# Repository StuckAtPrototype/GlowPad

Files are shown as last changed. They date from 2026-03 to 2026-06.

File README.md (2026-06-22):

# GlowPad

A multi-mode interactive pad built on the ESP32-S3 with 5 capacitive touch keys, 5 WS2812B LEDs, and a piezo buzzer. Supports five modes: a Pomodoro timer, a pentatonic piano, a Simon-style memory game, a reaction speed game, and a USB media-control (keyboard) mode for music players.

## Hardware

| Peripheral | Details |
|---|---|
| MCU | ESP32-S3-WROOM-1 |
| Touch inputs | 5 capacitive pads (CAP1-CAP5) on GPIO 4, 5, 3, 2, 1 |
| LEDs | 5x IN-PI15TAT5R5G5B (WS2812B) chain on GPIO 21 (via BSS138 level shifter) |
| Buzzer | Piezo (SMT1240SHT) on GPIO 48 (via transistor driver) |
| USB | Native USB-C (D+/D− on GPIO 20/19) for HID + programming |
| Power | AP2205 3.3V LDO |

### PCB / Design Files

The board is designed in [KiCad](https://www.kicad.org/) (v8+). Design sources and
manufacturing outputs live under `hardware/GlowPad/`:

| File / Folder | Contents |
|---|---|
| `GlowPad.kicad_pro` | KiCad project file |
| `GlowPad.kicad_sch` | Schematic |
| `GlowPad.kicad_pcb` | PCB layout |
| `GlowPad_BOM.csv` | Bill of materials |
| `gerber/` | Gerber + drill files for fabrication |

To open the design, launch KiCad and open `hardware/GlowPad/GlowPad.kicad_pro`.

#### Key components (see `GlowPad_BOM.csv` for the full BOM)

| Ref | Part | Function |
|---|---|---|
| U1 | ESP32-S3-WROOM-1 | MCU |
| U6 | AP2205-33 | 3.3V LDO regulator |
| Q1 | BSS138 | LED data level shifter |
| D5 | TPD1E10B06 | USB ESD protection |
| J1 | USB4105-GF-A | USB-C connector |
| LED1-5 | IN-PI15TAT5R5G5B | Addressable RGB LEDs |
| TCH1-5 | Capacitive pads | Touch keys |
| LS1 | SMT1240SHT | Piezo buzzer |
| SW1 / SW2 | RKB2 tactile | Reset / Boot (enable) |

## Modes

Switch modes by long-pressing keys 1–5 (pads 1–5).

### 1. Pomodoro Timer (key 1 long press)

A focus timer with five preset durations mapped to the five keys:

| Key | Duration |
|---|---|
| 1 | 5 min |
| 2 | 10 min |
| 3 | 25 min |
| 4 | 45 min |
| 5 | 60 min |

LEDs show a green progress bar while running. After the timer completes, a 60-second grace period starts (pulsing green). If not dismissed, it enters a 60-second alert with pulsing red LEDs and an audible jingle.

**Idle LEDs:** cyan at 30%.

### 2. Piano (key 2 long press)

Each key plays a note from the C-major pentatonic scale:

| Key | Note | Frequency |
|---|---|---|
| 1 | C5 | 523 Hz |
| 2 | D5 | 587 Hz |
| 3 | E5 | 659 Hz |
| 4 | G5 | 784 Hz |
| 5 | A5 | 880 Hz |

The corresponding LED flashes its colour at full brightness while the note plays, then fades back to a dim rainbow idle pattern.

**Idle LEDs:** rainbow (red, yellow, green, cyan, blue) at 20%.

### 3. Memory Game (key 3 long press)

A Simon-style memory game. The system plays an ever-growing random sequence of lights and tones. The player must repeat the sequence by pressing the matching keys in order.

- Each round adds one element to the sequence
- Correct presses flash the key's colour and play its tone
- Wrong press or 3-second timeout ends the game
- Score (rounds completed) is displayed on the LEDs at game over

**Idle LEDs:** yellow at 30%.

### 4. Reaction Game (key 4 long press)

A speed-and-accuracy reaction test over 5 rounds.

1. A random LED lights up after a random delay (0.5-1.5 seconds)
2. Press the matching key as fast as possible
3. Pressing before the LED appears counts as a false start (no penalty, round restarts)
4. After 5 rounds, the score is displayed as 0-5 green LEDs (one per "good" round)

A "good" round requires pressing the correct key in under 450ms. Per-round times and the total time are printed to the serial console.

**Idle LEDs:** purple at 30%.

### 5. Media Control (key 5 long press)

USB HID Consumer (media keys) mode. Connect GlowPad to the host via **native USB** (ESP32-S3 USB D+/D− on GPIO 20/19). The five pads act as media keys:

| Key | Action |
|---|---|
| 1 | Previous track |
| 2 | Play / Pause |
| 3 | Next track |
| 4 | Volume down |
| 5 | Volume up |

Works with most music players (Spotify, VLC, system media keys, etc.). Short press sends the key; the corresponding LED flashes for feedback.

**Idle LEDs:** orange/amber at 30%.

**Note:** Media mode requires the `esp_tinyusb` component (pulled in automatically) and HID enabled in menuconfig (`CONFIG_TINYUSB_HID_ENABLED`). The firmware uses a custom HID Consumer report descriptor.

## Building

Requires [ESP-IDF v5.5+](https://docs.espressif.com/projects/esp-idf/en/stable/esp32s3/get-started/).

```bash
cd GlowPad/firmware
idf.py set-target esp32s3
idf.py build
idf.py -p COMx flash monitor
```

## Project Structure

```
GlowPad/
├── firmware/                # ESP-IDF application
│   └── main/
│       ├── main.c              # Entry point, initialises peripherals and main loop
│       ├── mode_manager.c/h    # Mode switching and dispatch
│       ├── button.c/h          # Capacitive touch driver (ESP32-S3 touch sensor v2)
│       ├── led.c/h             # High-level LED control (progress bar, pulsing, per-LED colour)
│       ├── ws2812_control.c/h  # Low-level WS2812 RMT driver
│       ├── piezo.c/h           # Piezo buzzer driver (LEDC PWM)
│       ├── timer.c/h           # Pomodoro timer state machine
│       ├── piano.c/h           # Piano mode
│       ├── memory_game.c/h     # Simon-style memory game
│       ├── reaction_game.c/h   # Reaction speed game
│       ├── media_control.c/h   # USB HID media keys mode
│       ├── led_color_lib.c/h   # Colour generation utilities
│       └── serial_protocol.c/h # Serial protocol (placeholder)
└── hardware/
    └── GlowPad/             # KiCad project (schematic, PCB, BOM, gerbers)
```

## License

See [LICENSE](LICENSE).

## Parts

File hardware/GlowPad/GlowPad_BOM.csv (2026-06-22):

Id | Designator | Footprint | Quantity | Designation | Supplier and ref
1 | C18,C16,C2,C24,C25,C17 | C_0603_1608Metric | 6 | 0.1uF | CC0603KRX7R7BB104
2 | U1 | ESP32-S3-WROOM-1 | 1 | ESP32-S3-WROOM-1 | ESP32-S3-WROOM-1
3 | D5 | D_SOD-523 | 1 | TPD1E10B06 | TPD1E10B06DYAR
4 | TP1 | TestPoint_Pad_2.0x2.0mm | 1 | TestPoint | DNP
5 | R3,R6,R5 | R_0603_1608Metric | 3 | 470 | ESR03EZPF4700
6 | C1 | C_0603_1608Metric | 1 | 1uF | CC0603KRX5R8BB105
7 | C21,C22 | C_0603_1608Metric | 2 | 10uF | GRM188R61A106ME69D
8 | R4,R2,R1 | R_0603_1608Metric | 3 | 10K | WR06X103 JTL
9 | J1 | GCT_USB4105-GF-A | 1 | USB4105-GF-A | USB4105-GF-A
10 | R17,R18 | R_0603_1608Metric | 2 | 5K1 | RC0603FR-075K1L
11 | D1,D2 | LED_0603_1608Metric | 2 | LED | DNP
12 | TCH1,TCH2,TCH4,TCH5,TCH3 | CapButton_18_26 | 5 | ~ | DNP
13 | LED5,LED4,LED3,LED2,LED1 | IN-PI15_INL | 5 | IN-PI15TAT5R5G5B | IN-PI15TAT5R5G5B
14 | R16,R31 | R_0603_1608Metric | 2 | 1M | RMCF0603FT1M00
15 | U6 | AP2204 | 1 | AP2205 | AP2205-33W5-7
16 | SW1 | SWITCH_0SMTRLFS | 1 | SW_Reset | RKB2SJK250SMTR LFS
17 | SW2 | SWITCH_0SMTRLFS | 1 | SW_Enable | RKB2SJK250SMTR LFS
18 | Q1 | SOT-23 | 1 | BSS138 | BSS138
19 | C3 | C_0603_1608Metric | 1 | 47uF | GRM188C80E476ME05D
20 | LS1 | SMT1240SHT | 1 | SMT1240SHT | SMT1240SHT

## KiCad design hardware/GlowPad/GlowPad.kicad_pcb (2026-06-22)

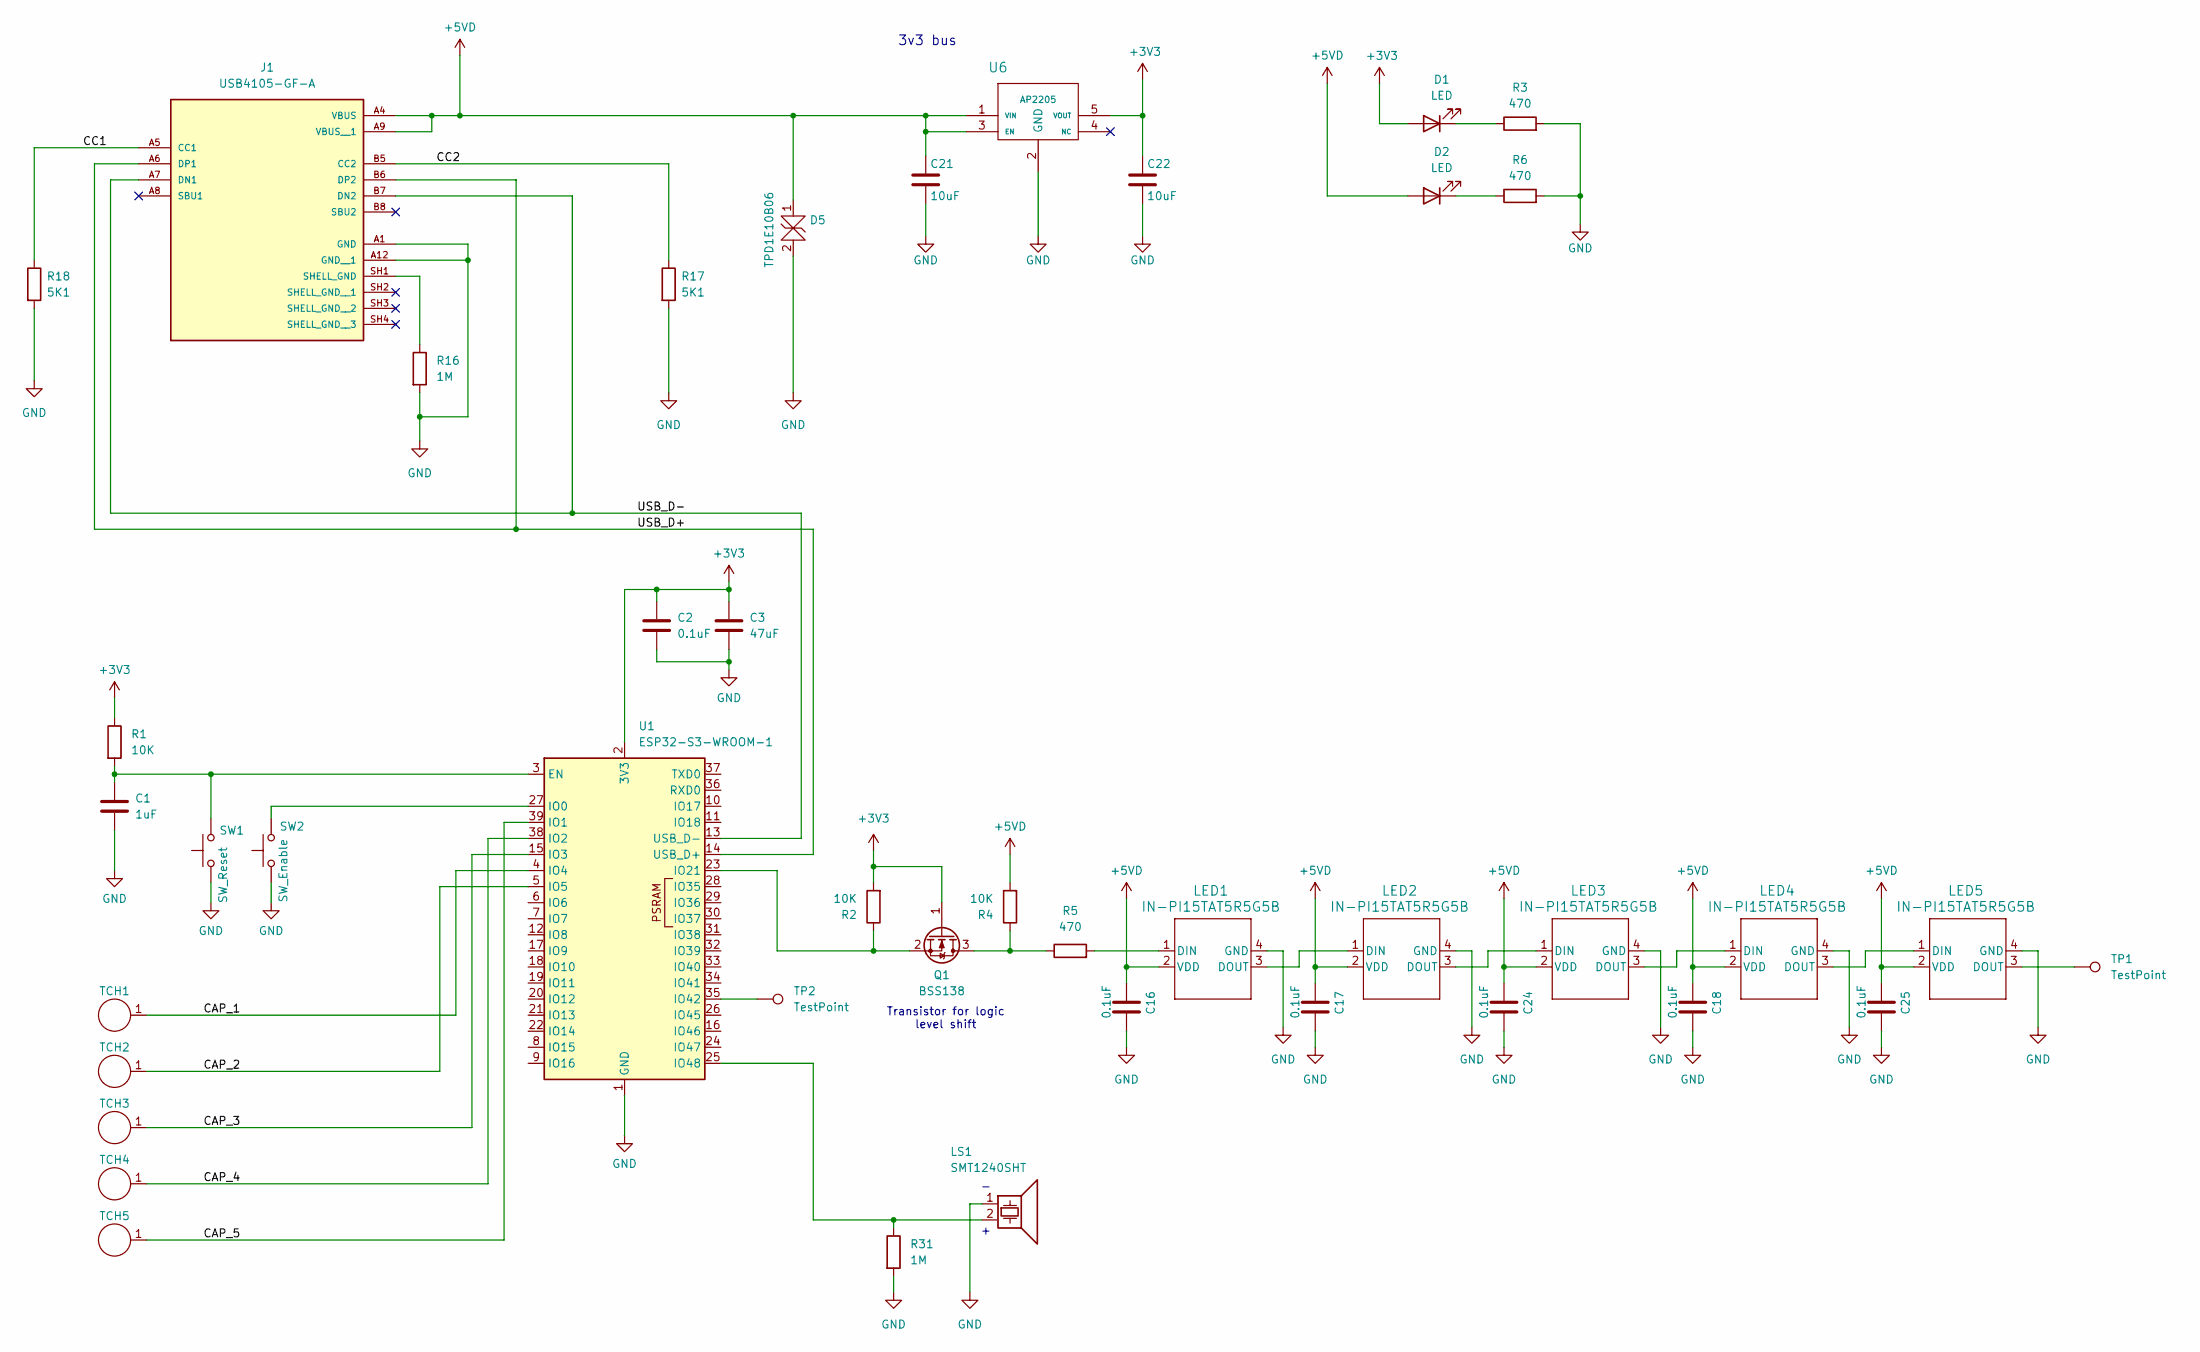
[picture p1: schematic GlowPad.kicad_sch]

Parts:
C1: 1uF; C_0603_1608Metric
C2, C16, C17, C18, C24, C25: 0.1uF; C_0603_1608Metric
C3: 47uF; C_0603_1608Metric
C21, C22: 10uF; C_0603_1608Metric
D1, D2: LED; LED_0603_1608Metric
D5: TPD1E10B06; D_SOD-523
J1: USB4105-GF-A; GCT_USB4105-GF-A; PARTREV B4
LED1, LED2, LED3, LED4, LED5: IN-PI15TAT5R5G5B; IN-PI15_INL
LS1: SMT1240SHT
Q1: BSS138; SOT-23
R1, R2, R4: 10K; R_0603_1608Metric
R3, R5, R6: 470; R_0603_1608Metric
R16, R31: 1M; R_0603_1608Metric
R17, R18: 5K1; R_0603_1608Metric
SW1: SW_Reset; SWITCH_0SMTRLFS
SW2: SW_Enable; SWITCH_0SMTRLFS
TCH1, TCH2, TCH3, TCH4, TCH5: CapButton_18_26
TP1, TP2: TestPoint; TestPoint_Pad_2.0x2.0mm
U1: ESP32-S3-WROOM-1
U6: AP2205; AP2204

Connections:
+3V3: C2.1, C3.1, C22.1, D1.2 (A), Q1.1 (G), R1.1, R2.2, U1.2 (3V3), U6.5 (VOUT)
+5VD: C16.1, C17.1, C18.1, C21.1, C24.1, C25.1, D2.2 (A), D5.1, J1.A4 (VBUS), J1.A9 (VBUS__1), LED1.2 (VDD), LED2.2 (VDD), LED3.2 (VDD), LED4.2 (VDD), LED5.2 (VDD), R4.2, U6.1 (VIN), U6.3 (EN)
/CAP_1: TCH1.1, U1.4 (IO4)
/CAP_2: TCH2.1, U1.5 (IO5)
/CAP_3: TCH3.1, U1.15 (IO3)
/CAP_4: TCH4.1, U1.38 (IO2)
/CAP_5: TCH5.1, U1.39 (IO1)
/CC1: J1.A5 (CC1), R18.1
/CC2: J1.B5 (CC2), R17.1
/USB_D+: J1.A6 (DP1), J1.B6 (DP2), U1.14 (USB_D+)
/USB_D-: J1.A7 (DN1), J1.B7 (DN2), U1.13 (USB_D-)
GND: C1.2, C2.2, C3.2, C16.2, C17.2, C18.2, C21.2, C22.2, C24.2, C25.2, D5.2, J1.A1 (GND), J1.A12 (GND__1), LED1.4 (GND), LED2.4 (GND), LED3.4 (GND), LED4.4 (GND), LED5.4 (GND), LS1.1, R3.2, R6.2, R16.2, R17.2, R18.2, R31.2, SW1.1, SW2.1, U1.1 (GND), U1.40 (GND), U1.41 (GND), U6.2 (GND)
unnamed: D1.1 (K), R3.1
unnamed: D2.1 (K), R6.1
unnamed: J1.SH1 (SHELL_GND), R16.1
unnamed: LED1.1 (DIN), R5.2
unnamed: LED1.3 (DOUT), LED2.1 (DIN)
unnamed: LED2.3 (DOUT), LED3.1 (DIN)
unnamed: LED3.3 (DOUT), LED4.1 (DIN)
unnamed: LED4.3 (DOUT), LED5.1 (DIN)
unnamed: LED5.3 (DOUT), TP1.1
unnamed: Q1.3 (D), R4.1, R5.1
unnamed: Q1.2 (S), R2.1, U1.23 (IO21)
unnamed: C1.1, R1.2, SW1.2, U1.3 (EN)
unnamed: SW2.2, U1.27 (IO0)
unnamed: TP2.1, U1.35 (IO42)
unnamed: LS1.2, R31.1, U1.25 (IO48)

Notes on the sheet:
Transistor for logic level shift
3v3 bus

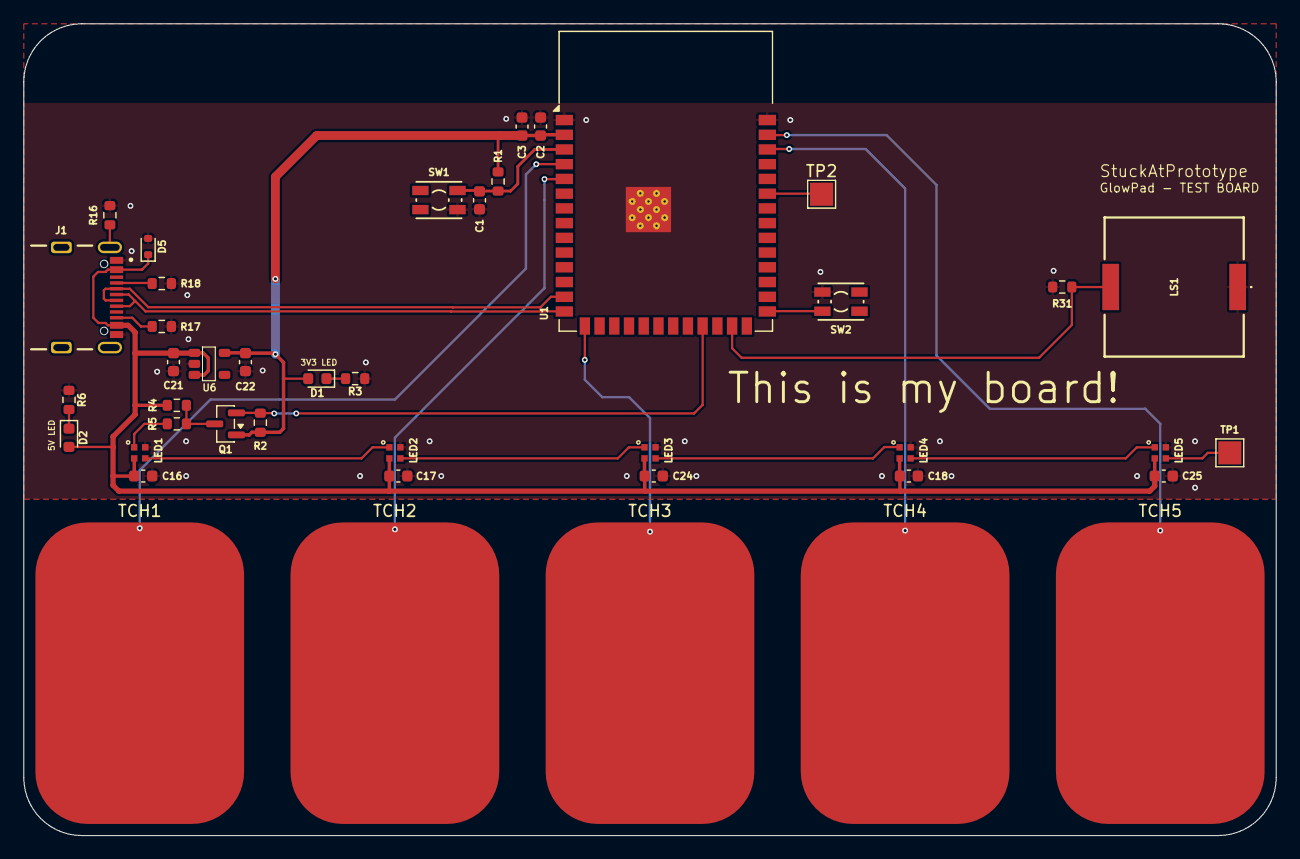
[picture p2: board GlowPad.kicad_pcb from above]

Board: 2 copper layers, 108.0 x 70.0 mm, 42 parts (0 on the bottom side), 27 nets.

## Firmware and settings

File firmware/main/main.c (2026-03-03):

#include "freertos/FreeRTOS.h"
#include "freertos/task.h"
#include "esp_log.h"
#include "nvs_flash.h"
#include "led.h"
#include "button.h"
#include "timer.h"
#include "piezo.h"
#include "mode_manager.h"

static const char *TAG = "main";
static TaskHandle_t main_task_handle = NULL;

static void button_event_handler(uint8_t button_id, button_press_type_t press_type)
{
    bool is_long_press = (press_type == BUTTON_PRESS_LONG);
    mode_manager_handle_button(button_id, is_long_press);

    if (main_task_handle != NULL) {
        xTaskNotifyGive(main_task_handle);
    }
}

void app_main(void)
{
    main_task_handle = xTaskGetCurrentTaskHandle();

    ESP_LOGI(TAG, "GlowPad Starting");

    // Initialize NVS
    esp_err_t ret = nvs_flash_init();
    if (ret == ESP_ERR_NVS_NO_FREE_PAGES || ret == ESP_ERR_NVS_NEW_VERSION_FOUND) {
        ESP_ERROR_CHECK(nvs_flash_erase());
        ret = nvs_flash_init();
    }
    ESP_ERROR_CHECK(ret);

    // Peripherals
    led_init();
    if (piezo_init() == 0) {
        piezo_play_startup_jingle();
    }
    button_init();
    button_register_callback(button_event_handler);
    timer_init();

    // Mode manager (starts in Pomodoro)
    mode_manager_init();
    led_clear_all();

    ESP_LOGI(TAG, "GlowPad Ready");

    // Main loop
    while (1) {
        ulTaskNotifyTake(pdTRUE, pdMS_TO_TICKS(100));
        mode_manager_update();
    }
}

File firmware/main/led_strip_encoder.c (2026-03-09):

/*
 * SPDX-FileCopyrightText: 2021-2022 Espressif Systems (Shanghai) CO LTD
 *
 * SPDX-License-Identifier: Apache-2.0
 */

#include "esp_check.h"
#include "led_strip_encoder.h"

static const char *TAG = "led_encoder";

typedef struct {
    rmt_encoder_t base;
    rmt_encoder_t *bytes_encoder;
    rmt_encoder_t *copy_encoder;
    int state;
    rmt_symbol_word_t reset_code;
} rmt_led_strip_encoder_t;

RMT_ENCODER_FUNC_ATTR
static size_t rmt_encode_led_strip(rmt_encoder_t *encoder, rmt_channel_handle_t channel, const void *primary_data, size_t data_size, rmt_encode_state_t *ret_state)
{
    rmt_led_strip_encoder_t *led_encoder = __containerof(encoder, rmt_led_strip_encoder_t, base);
    rmt_encoder_handle_t bytes_encoder = led_encoder->bytes_encoder;
    rmt_encoder_handle_t copy_encoder = led_encoder->copy_encoder;
    rmt_encode_state_t session_state = RMT_ENCODING_RESET;
    rmt_encode_state_t state = RMT_ENCODING_RESET;
    size_t encoded_symbols = 0;
    switch (led_encoder->state) {
    case 0:
        encoded_symbols += bytes_encoder->encode(bytes_encoder, channel, primary_data, data_size, &session_state);
        if (session_state & RMT_ENCODING_COMPLETE) {
            led_encoder->state = 1;
        }
        if (session_state & RMT_ENCODING_MEM_FULL) {
            state |= RMT_ENCODING_MEM_FULL;
            goto out;
        }
    // fall-through
    case 1:
        encoded_symbols += copy_encoder->encode(copy_encoder, channel, &led_encoder->reset_code,
                                                sizeof(led_encoder->reset_code), &session_state);
        if (session_state & RMT_ENCODING_COMPLETE) {
            led_encoder->state = RMT_ENCODING_RESET;
            state |= RMT_ENCODING_COMPLETE;
        }
        if (session_state & RMT_ENCODING_MEM_FULL) {
            state |= RMT_ENCODING_MEM_FULL;
            goto out;
        }
    }
out:
    *ret_state = state;
    return encoded_symbols;
}

static esp_err_t rmt_del_led_strip_encoder(rmt_encoder_t *encoder)
{
    rmt_led_strip_encoder_t *led_encoder = __containerof(encoder, rmt_led_strip_encoder_t, base);
    rmt_del_encoder(led_encoder->bytes_encoder);
    rmt_del_encoder(led_encoder->copy_encoder);
    free(led_encoder);
    return ESP_OK;
}

RMT_ENCODER_FUNC_ATTR
static esp_err_t rmt_led_strip_encoder_reset(rmt_encoder_t *encoder)
{
    rmt_led_strip_encoder_t *led_encoder = __containerof(encoder, rmt_led_strip_encoder_t, base);
    rmt_encoder_reset(led_encoder->bytes_encoder);
    rmt_encoder_reset(led_encoder->copy_encoder);
    led_encoder->state = RMT_ENCODING_RESET;
    return ESP_OK;
}

esp_err_t rmt_new_led_strip_encoder(const led_strip_encoder_config_t *config, rmt_encoder_handle_t *ret_encoder)
{
    esp_err_t ret = ESP_OK;
    rmt_led_strip_encoder_t *led_encoder = NULL;
    ESP_GOTO_ON_FALSE(config && ret_encoder, ESP_ERR_INVALID_ARG, err, TAG, "invalid argument");
    led_encoder = rmt_alloc_encoder_mem(sizeof(rmt_led_strip_encoder_t));
    ESP_GOTO_ON_FALSE(led_encoder, ESP_ERR_NO_MEM, err, TAG, "no mem for led strip encoder");
    led_encoder->base.encode = rmt_encode_led_strip;
    led_encoder->base.del = rmt_del_led_strip_encoder;
    led_encoder->base.reset = rmt_led_strip_encoder_reset;
    rmt_bytes_encoder_config_t bytes_encoder_config = {
        .bit0 = {
            .level0 = 1,
            .duration0 = 0.3 * config->resolution / 1000000, // T0H=0.3us
            .level1 = 0,
            .duration1 = 0.9 * config->resolution / 1000000, // T0L=0.9us
        },
        .bit1 = {
            .level0 = 1,
            .duration0 = 0.9 * config->resolution / 1000000, // T1H=0.9us
            .level1 = 0,
            .duration1 = 0.3 * config->resolution / 1000000, // T1L=0.3us
        },
        .flags.msb_first = 1
    };
    ESP_GOTO_ON_ERROR(rmt_new_bytes_encoder(&bytes_encoder_config, &led_encoder->bytes_encoder), err, TAG, "create bytes encoder failed");
    rmt_copy_encoder_config_t copy_encoder_config = {};
    ESP_GOTO_ON_ERROR(rmt_new_copy_encoder(&copy_encoder_config, &led_encoder->copy_encoder), err, TAG, "create copy encoder failed");

    uint32_t reset_ticks = config->resolution / 1000000 * 50 / 2;
    led_encoder->reset_code = (rmt_symbol_word_t) {
        .level0 = 0,
        .duration0 = reset_ticks,
        .level1 = 0,
        .duration1 = reset_ticks,
    };
    *ret_encoder = &led_encoder->base;
    return ESP_OK;
err:
    if (led_encoder) {
        if (led_encoder->bytes_encoder) {
            rmt_del_encoder(led_encoder->bytes_encoder);
        }
        if (led_encoder->copy_encoder) {
            rmt_del_encoder(led_encoder->copy_encoder);
        }
        free(led_encoder);
    }
    return ret;
}

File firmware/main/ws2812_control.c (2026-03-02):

/**
 * @file ws2812_control.c
 * @brief WS2812 LED strip control implementation
 * 
 * This file implements the low-level control for WS2812 addressable LED strips
 * using the ESP32's RMT (Remote Control) peripheral. It provides initialization
 * and data transmission functions for controlling individual LEDs in the strip.
 * 
 * @author StuckAtPrototype, LLC
 * @version 3.0
 */

#include "ws2812_control.h"
#include "driver/rmt_tx.h"
#include "esp_err.h"
#include "esp_check.h"
#include "freertos/FreeRTOS.h"
#include "esp_log.h"

// Hardware configuration
#define LED_RMT_TX_GPIO         21  // GPIO pin for LED data output (through BSS138 level shifter)
#define BITS_PER_LED_CMD        24  // 24 bits per LED (8 bits each for R, G, B)
#define LED_BUFFER_ITEMS        (NUM_LEDS * BITS_PER_LED_CMD)

// WS2812 timing parameters (assuming 10MHz RMT resolution)
#define T0H     3  // 0 bit high time (0.3μs)
#define T1H     6  // 1 bit high time (0.6μs)
#define T0L     8  // 0 bit low time (0.8μs)
#define T1L     5  // 1 bit low time (0.5μs)

static const char *TAG = "NeoPixel WS2812 Driver";

// Global variables for RMT control
static rmt_channel_handle_t led_chan = NULL;      // RMT channel handle
static rmt_encoder_handle_t led_encoder = NULL;   // RMT encoder handle
static uint8_t led_data_buffer[NUM_LEDS * 3];     // Buffer for LED data (3 bytes per LED: RGB)

/**
 * @brief RMT encoder wrapper function
 * 
 * This function wraps the bytes encoder for RMT transmission.
 * It's used internally by the RMT driver to encode data for transmission.
 * 
 * @param encoder RMT encoder handle
 * @param channel RMT channel handle
 * @param primary_data Data to encode
 * @param data_size Size of data to encode
 * @param ret_state Return state pointer
 * @return Number of encoded symbols
 */
static size_t ws2812_rmt_encode(rmt_encoder_t *encoder, rmt_channel_handle_t channel, const void *primary_data, size_t data_size, rmt_encode_state_t *ret_state)
{
    rmt_encoder_handle_t bytes_encoder = (rmt_encoder_handle_t)encoder;
    rmt_encode_state_t session_state = 0;
    size_t encoded_symbols = bytes_encoder->encode(bytes_encoder, channel, primary_data, data_size, &session_state);
    *ret_state = session_state;
    return encoded_symbols;
}

/**
 * @brief Initialize WS2812 LED control system
 * 
 * This function initializes the RMT (Remote Control) peripheral for controlling
 * WS2812 LED strips. It configures the RMT channel, sets up the timing parameters
 * for WS2812 protocol, and creates the necessary encoders.
 * 
 * @return ESP_OK on success, error code on failure
 */
esp_err_t ws2812_control_init(void)
{
    ESP_LOGI(TAG, "Create RMT TX channel");
    rmt_tx_channel_config_t tx_chan_config = {
            .gpio_num = LED_RMT_TX_GPIO,           // GPIO pin for LED data
            .clk_src = RMT_CLK_SRC_DEFAULT,        // Use default clock source
            .resolution_hz = 10 * 1000 * 1000,     // 10MHz resolution for precise timing
            .mem_block_symbols = 64,               // Memory block size
            .trans_queue_depth = 4,                // Transmission queue depth
    };
    ESP_RETURN_ON_ERROR(rmt_new_tx_channel(&tx_chan_config, &led_chan), TAG, "Failed to create RMT TX channel");

    ESP_LOGI(TAG, "Install led strip encoder");
    rmt_bytes_encoder_config_t bytes_encoder_config = {
            .bit0 = {
                    .level0 = 1,        // High level for '0' bit
                    .duration0 = T0H,   // High duration for '0' bit
                    .level1 = 0,        // Low level for '0' bit
                    .duration1 = T0L,   // Low duration for '0' bit
            },
            .bit1 = {
                    .level0 = 1,        // High level for '1' bit
                    .duration0 = T1H,   // High duration for '1' bit
                    .level1 = 0,        // Low level for '1' bit
                    .duration1 = T1L,   // Low duration for '1' bit
            },
            .flags.msb_first = 1,       // Send MSB first
    };
    ESP_RETURN_ON_ERROR(rmt_new_bytes_encoder(&bytes_encoder_config, &led_encoder), TAG, "Failed to create bytes encoder");

    ESP_LOGI(TAG, "Enable RMT TX channel");
    ESP_RETURN_ON_ERROR(rmt_enable(led_chan), TAG, "Failed to enable RMT channel");

    return ESP_OK;
}

/**
 * @brief Write LED data to WS2812 strip
 * 
 * This function takes a structure containing LED color data and transmits it
 * to the WS2812 LED strip using the RMT peripheral. It converts the 24-bit
 * color values to the proper byte format and sends them via RMT.
 * 
 * @param new_state Structure containing color data for all LEDs
 * @return ESP_OK on success, error code on failure
 */
esp_err_t ws2812_write_leds(struct led_state new_state)
{
    // Convert 24-bit color values to RGB byte format
    for (uint32_t led = 0; led < NUM_LEDS; led++) {
        uint32_t bits_to_send = new_state.leds[led];
        led_data_buffer[led * 3 + 0] = (bits_to_send >> 16) & 0xFF; // Red component
        led_data_buffer[led * 3 + 1] = (bits_to_send >> 8) & 0xFF;  // Green component
        led_data_buffer[led * 3 + 2] = bits_to_send & 0xFF;         // Blue component
    }

    // Configure transmission parameters
    rmt_transmit_config_t tx_config = {
            .loop_count = 0,  // No looping
    };

    // Transmit the LED data via RMT
    ESP_RETURN_ON_ERROR(rmt_transmit(led_chan, led_encoder, led_data_buffer, sizeof(led_data_buffer), &tx_config), TAG, "Failed to transmit RMT data");
    
    // Wait for transmission to complete
    ESP_RETURN_ON_ERROR(rmt_tx_wait_all_done(led_chan, portMAX_DELAY), TAG, "Failed to wait for RMT transmission to finish");

    return ESP_OK;
}
